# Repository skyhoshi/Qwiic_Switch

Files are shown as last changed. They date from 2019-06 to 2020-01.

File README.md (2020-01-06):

SparkFun Qwiic Switch/Arcade
========================================
<table class="table table-hover table-striped table-bordered">
  <tr align="center">
   <td></td>
   <td></td>
   <td></td>
  </tr>
  <tr align="center">
    <td><a href="https://www.sparkfun.com/products/15591">SparkFun Qwiic Arcade - Red (SPX-15591)</a></td>
    <td><a href="https://www.sparkfun.com/products/15592">SparkFun Qwiic Arcade - Blue (SPX-15592)</a></td>
    <td><a href="https://www.sparkfun.com/products/15586">SparkFun Qwiic Switch (SPX-15586)</a></td>
  </tr>
</table>

The SparkFun Qwiic Switch and Qwiic Arcade are I<sup>2</sup>C enabled boards with interrupts, variable I<sup>2</sup>C addresses, external LED output, and onboard button queues.

Repository Contents
-------------------

* **/Firmware** - Firmware for the built-in ATTiny84 on the Qwiic Button/Switch/Arcade (.h, .ino)
* **/Hardware** - Eagle design files (.brd, .sch)
* **/Hardware/Production** - Production panel files (.brd)

Documentation
--------------
* **[SparkFun Qwiic Button Arduino Library](https://github.com/sparkfun/SparkFun_Qwiic_Button_Arduino_Library)** - Arduino library for the Qwiic Button and Switch.

License Information
-------------------

This product is _**open source**_! 

Please review the LICENSE.md file for license information. 

If you have any questions or concerns on licensing, please contact technical support on our [SparkFun forums](https://forum.sparkfun.com/viewforum.php?f=152).

Distributed as-is; no warranty is given.

- Your friends at SparkFun.

_<COLLABORATION CREDIT>_

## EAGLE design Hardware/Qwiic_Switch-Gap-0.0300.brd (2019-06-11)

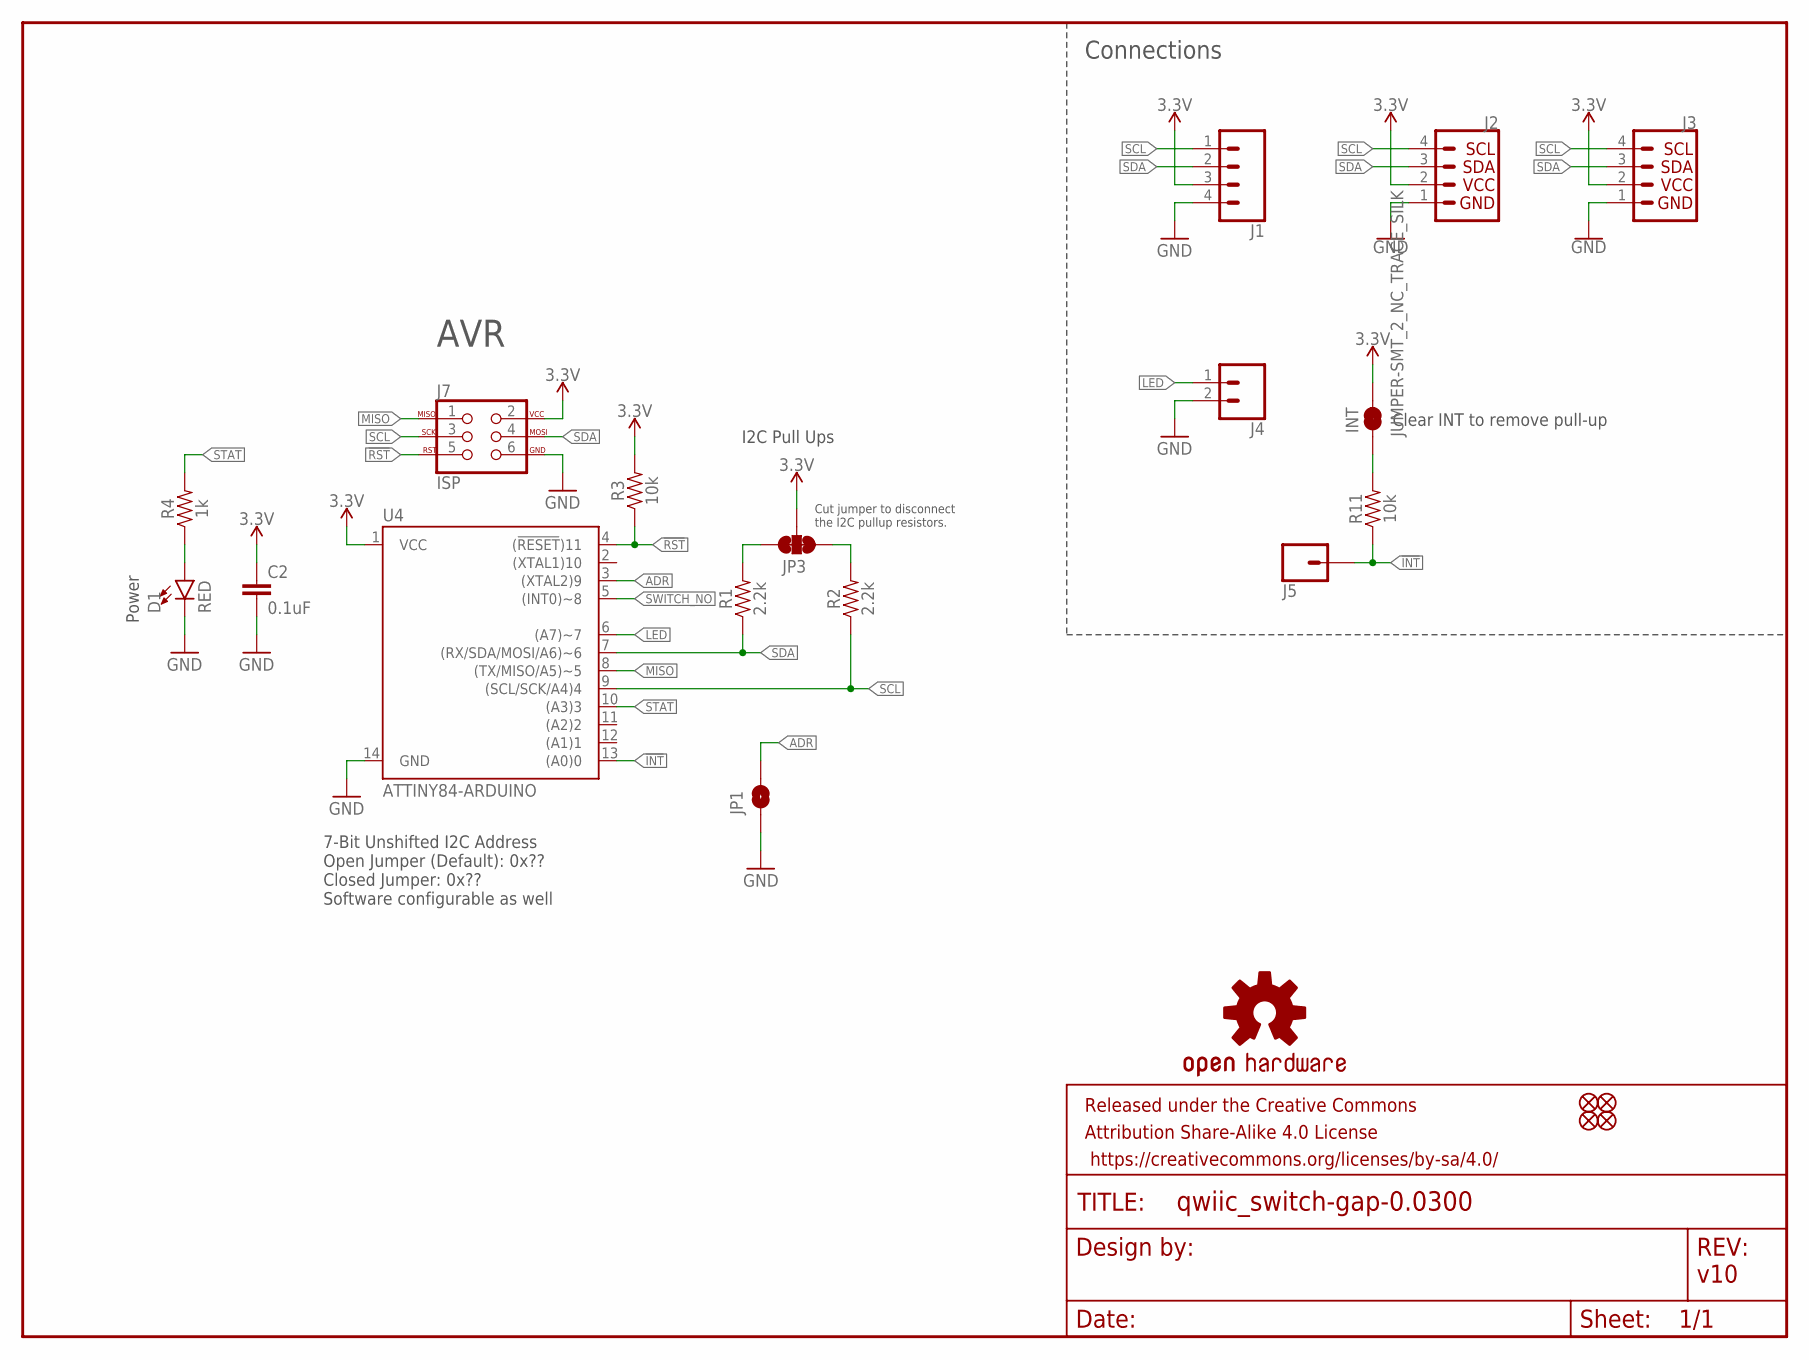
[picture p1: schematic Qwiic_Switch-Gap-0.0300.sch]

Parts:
C2: 0.1uF; 0603
D1: RED; LED-0603
FRAME1: FRAME-LETTER; CREATIVE_COMMONS
INT: JUMPER-SMT_2_NC_TRACE_SILK; SMT-JUMPER_2_NC_TRACE_SILK
J1: CONN_041X04_NO_SILK; 1X04_NO_SILK
J2, J3: QWIIC_CONNECTORJS-1MM; JST04_1MM_RA
J4: CONN_021X02_NO_SILK; 1X02_NO_SILK
J5: CONN_01PTH_NO_SILK_YES_STOP; 1X01_NO_SILK
J7: ISP; 2X3_TEST_POINTS
JP1: JUMPER-SMT_2_NO_SILK; SMT-JUMPER_2_NO_SILK
JP2, JP6, JP8, JP9: FIDUCIALUFIDUCIAL; MICRO-FIDUCIAL
JP3: JUMPER-SMT_3_2-NC_TRACE_SILK; SMT-JUMPER_3_2-NC_TRACE_SILK
LOGO1: OSHW-LOGOMINI; OSHW-LOGO-MINI
R1, R2: 2.2k; 0603
R3, R11: 10k; 0603
R4: 1k; 0603
U4: ATTINY84-ARDUINO; SO14

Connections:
3.3V: C2.1, INT.2, J1.3, J2.2, J3.2, J7.2, JP3.2, R3.2, U4.1 (VCC)
!INT: J5.1, R11.1, U4.13 ((A0)0)
!RST: J7.5, R3.1, U4.4 ((!RESET!)11)
ADR: JP1.2, U4.3 ((XTAL2)9)
GND: C2.2, D1.C, J1.4, J2.1, J3.1, J4.2, J7.6, JP1.1, U4.14 (GND)
INT_R: INT.1, R11.2
LED: J4.1, U4.6 ((A7)~7)
MISO: J7.1, U4.8 ((TX/MISO/A5)~5)
unnamed: D1.A, R4.1
SCL: J1.1, J2.4, J3.4, J7.3, R2.1, U4.9 ((SCL/SCK/A4)4)
SCL_PU1: JP3.1, R2.2
SDA: J1.2, J2.3, J3.3, J7.4, R1.1, U4.7 ((RX/SDA/MOSI/A6)~6)
SDA_PU1: JP3.3, R1.2
STAT: R4.2, U4.10 ((A3)3)
SWITCH_NO: U4.5 ((INT0)~8)

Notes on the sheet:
v10
Connections
Cut jumper to disconnect the I2C pullup resistors.
7-Bit Unshifted I2C Address Open Jumper (Default): 0x?? Closed Jumper: 0x?? Software configurable as well
I2C Pull Ups
AVR
Power
Clear INT to remove pull-up

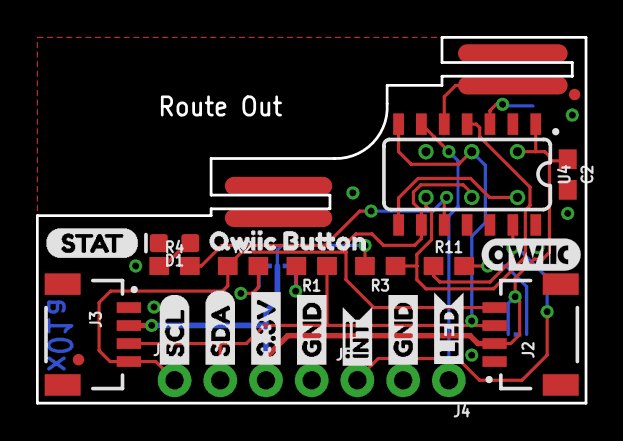
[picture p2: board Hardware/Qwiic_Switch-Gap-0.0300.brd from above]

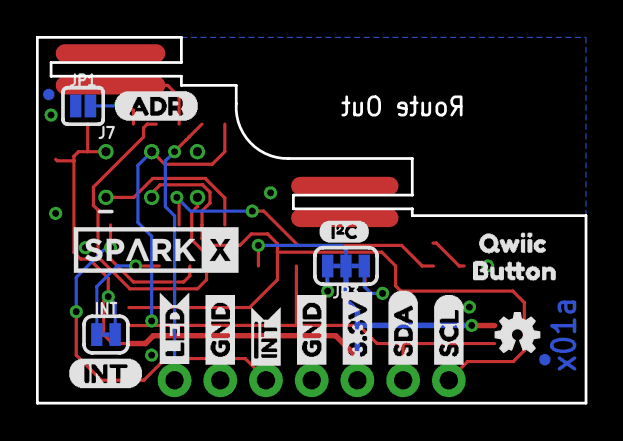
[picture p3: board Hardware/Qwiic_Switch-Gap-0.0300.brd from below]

Board: 2 copper layers, 30.5 x 20.3 mm, 47 parts (20 on the bottom side), 14 nets.

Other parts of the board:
U$1: QWIIC_5.5MM
U$2, U$20: QWIIC0
U$3, U$19: LED2
U$4: INT-()-04
U$5, U$14: SCL
U$6, U$12: SDA
U$7, U$22: 3.3V
U$8, U$13, U$16, U$17: GND
U$9: (ADR)
U$10: I_SUPER2_C-()-03
U$11, U$15: INT#-[<-04
U$18: SPARKX-MEDIUM
U$21: STAT1
U$23, U$24: BUTTON1

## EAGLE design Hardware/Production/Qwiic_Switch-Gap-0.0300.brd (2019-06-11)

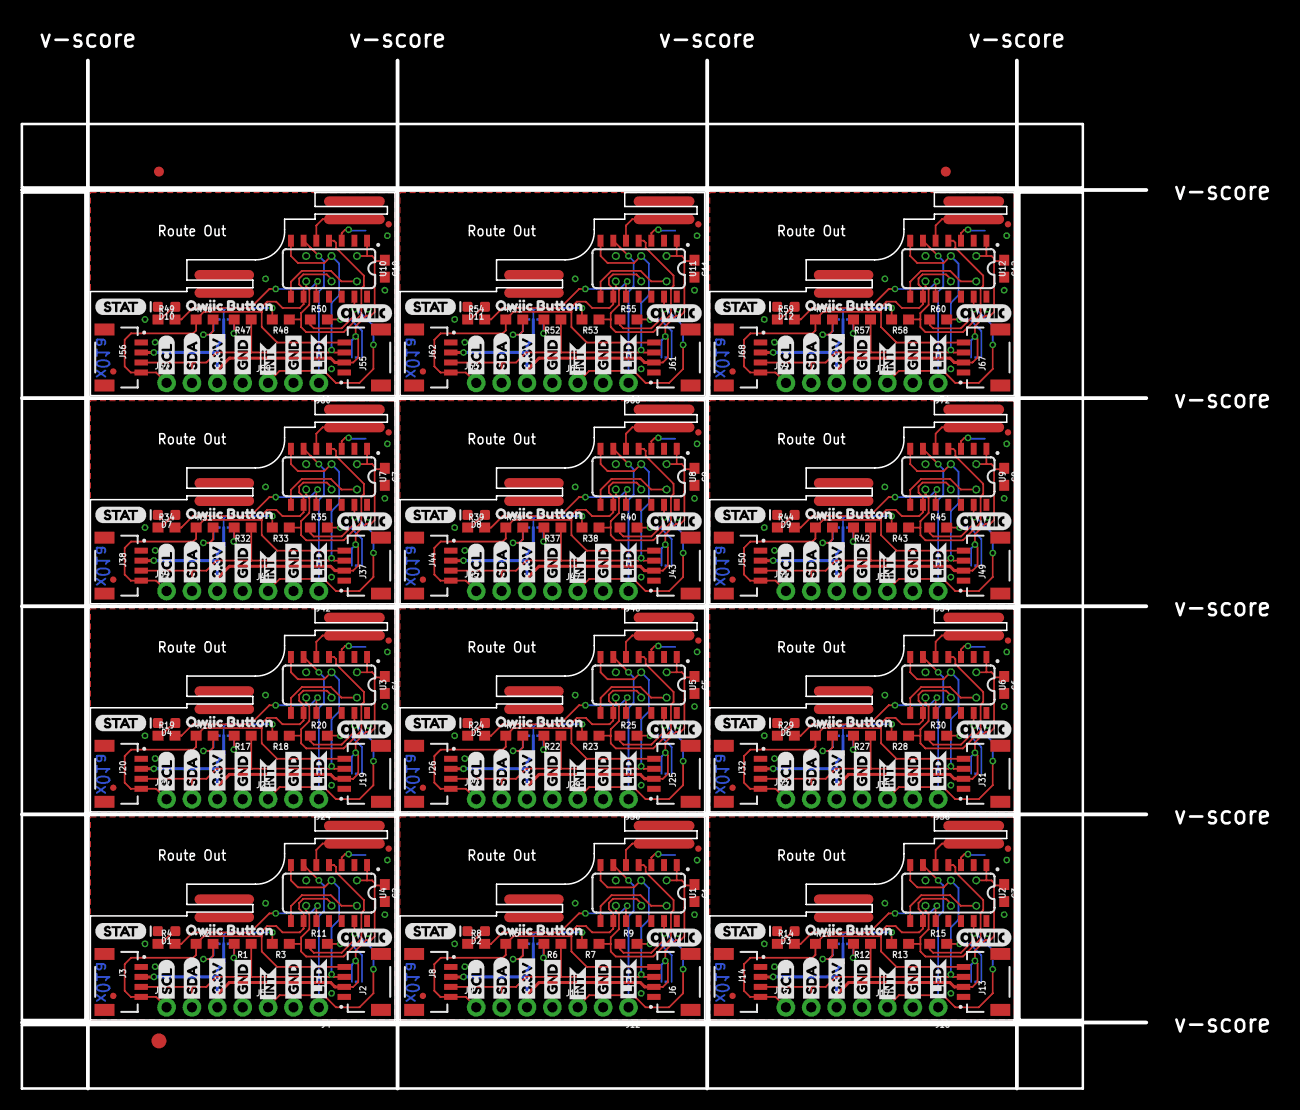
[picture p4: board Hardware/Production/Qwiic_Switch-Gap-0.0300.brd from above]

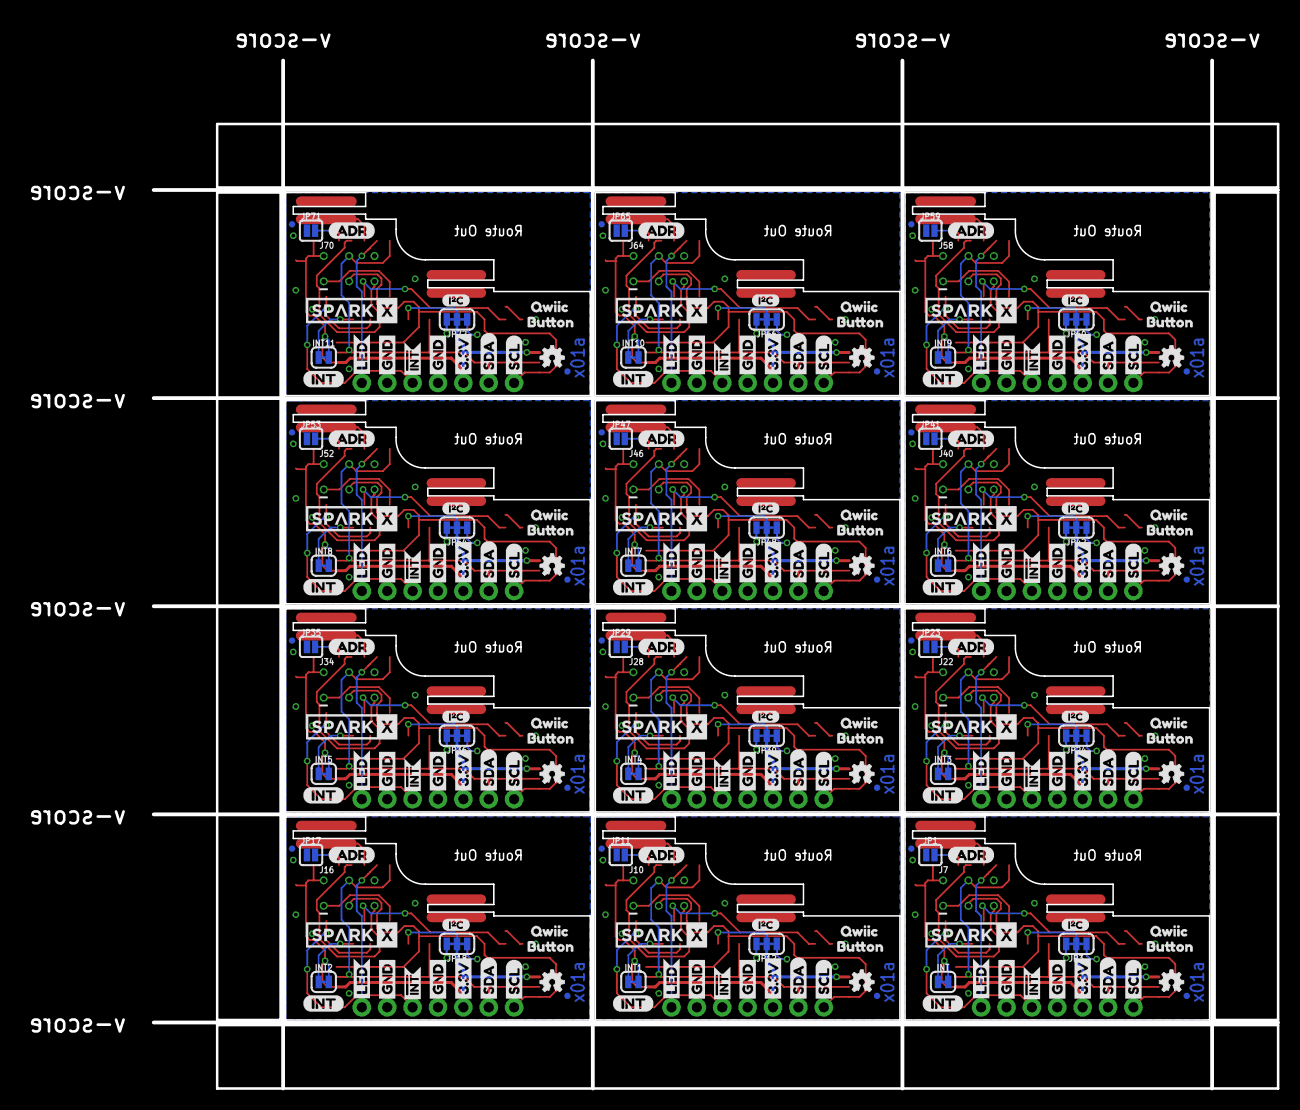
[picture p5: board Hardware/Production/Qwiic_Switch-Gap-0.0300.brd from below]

Board: 2 copper layers, 112.5 x 102.9 mm, 555 parts (240 on the bottom side), 168 nets.

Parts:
C1, C2, C3, C4, C5, C6, C7, C8, C9, C10, C11, C12: 0.1uF; 0603
D1, D2, D3, D4, D5, D6, D7, D8, D9, D10, D11, D12: RED; LED-0603
E$1, E$2: FIDUCIAL-1X2
E$3: FIDUCIAL-1.5X3
INT, INT1, INT2, INT3, INT4, INT5, INT6, INT7, INT8, INT9, INT10, INT11: JUMPER-SMT_2_NC_TRACE_SILK; SMT-JUMPER_2_NC_TRACE_SILK
J1, J9, J15, J21, J27, J33, J39, J45, J51, J57, J63, J69: 1X04_NO_SILK
J2, J3, J6, J8, J13, J14, J19, J20, J25, J26, J31, J32, J37, J38, J43, J44, J49, J50, J55, J56, J61, J62, J67, J68: JST04_1MM_RA
J4, J12, J18, J24, J30, J36, J42, J48, J54, J60, J66, J72: 1X02_NO_SILK
J5, J11, J17, J23, J29, J35, J41, J47, J53, J59, J65, J71: 1X01_NO_SILK
J7, J10, J16, J22, J28, J34, J40, J46, J52, J58, J64, J70: ISP; 2X3_TEST_POINTS
JP1, JP11, JP17, JP23, JP29, JP35, JP41, JP47, JP53, JP59, JP65, JP71: SMT-JUMPER_2_NO_SILK
JP2, JP4, JP5, JP6, JP7, JP8, JP9, JP10, JP13, JP14, JP15, JP16, JP19, JP20, JP21, JP22, JP25, JP26, JP27, JP28, JP31, JP32, JP33, JP34, JP37, JP38, JP39, JP40, JP43, JP44, JP45, JP46, JP49, JP50, JP51, JP52, JP55, JP56, JP57, JP58, JP61, JP62, JP63, JP64, JP67, JP68, JP69, JP70: FIDUCIALUFIDUCIAL; MICRO-FIDUCIAL
JP3, JP12, JP18, JP24, JP30, JP36, JP42, JP48, JP54, JP60, JP66, JP72: SMT-JUMPER_3_2-NC_TRACE_SILK
LOGO1, LOGO2, LOGO3, LOGO4, LOGO5, LOGO6, LOGO7, LOGO8, LOGO9, LOGO10, LOGO11, LOGO12: OSHW-LOGOMINI; OSHW-LOGO-MINI
R1, R2, R5, R6, R10, R12, R16, R17, R21, R22, R26, R27, R31, R32, R36, R37, R41, R42, R46, R47, R51, R52, R56, R57: 2.2k; 0603
R3, R7, R9, R11, R13, R15, R18, R20, R23, R25, R28, R30, R33, R35, R38, R40, R43, R45, R48, R50, R53, R55, R58, R60: 10k; 0603
R4, R8, R14, R19, R24, R29, R34, R39, R44, R49, R54, R59: 1k; 0603
U1, U2, U3, U4, U5, U6, U7, U8, U9, U10, U11, U12: ATTINY84-ARDUINO; SO14
U$1, U$44, U$68, U$92, U$116, U$140, U$164, U$188, U$212, U$236, U$260, U$284: QWIIC_5.5MM
U$2, U$20, U$45, U$46, U$69, U$70, U$93, U$94, U$117, U$118, U$141, U$142, U$165, U$166, U$189, U$190, U$213, U$214, U$237, U$238, U$261, U$262, U$285, U$286: QWIIC0
U$3, U$19, U$41, U$42, U$65, U$66, U$89, U$90, U$113, U$114, U$137, U$138, U$161, U$162, U$185, U$186, U$209, U$210, U$233, U$234, U$257, U$258, U$281, U$282: LED2
U$4, U$40, U$64, U$88, U$112, U$136, U$160, U$184, U$208, U$232, U$256, U$280: INT-()-04
U$5, U$14, U$25, U$35, U$49, U$59, U$73, U$83, U$97, U$107, U$121, U$131, U$145, U$155, U$169, U$179, U$193, U$203, U$217, U$227, U$241, U$251, U$265, U$275: SCL
U$6, U$12, U$26, U$34, U$50, U$58, U$74, U$82, U$98, U$106, U$122, U$130, U$146, U$154, U$170, U$178, U$194, U$202, U$218, U$226, U$242, U$250, U$266, U$274: SDA
U$7, U$22, U$27, U$31, U$51, U$55, U$75, U$79, U$99, U$103, U$123, U$127, U$147, U$151, U$171, U$175, U$195, U$199, U$219, U$223, U$243, U$247, U$267, U$271: 3.3V
U$8, U$13, U$16, U$17, U$28, U$30, U$37, U$38, U$52, U$54, U$61, U$62, U$76, U$78, U$85, U$86, U$100, U$102, U$109, U$110, U$124, U$126, U$133, U$134, U$148, U$150, U$157, U$158, U$172, U$174, U$181, U$182, U$196, U$198, U$205, U$206, U$220, U$222, U$229, U$230, U$244, U$246, U$253, U$254, U$268, U$270, U$277, U$278: GND
U$9, U$29, U$53, U$77, U$101, U$125, U$149, U$173, U$197, U$221, U$245, U$269: (ADR)
U$10, U$32, U$56, U$80, U$104, U$128, U$152, U$176, U$200, U$224, U$248, U$272: I_SUPER2_C-()-03
U$11, U$15, U$33, U$36, U$57, U$60, U$81, U$84, U$105, U$108, U$129, U$132, U$153, U$156, U$177, U$180, U$201, U$204, U$225, U$228, U$249, U$252, U$273, U$276: INT#-[<-04
U$18, U$39, U$63, U$87, U$111, U$135, U$159, U$183, U$207, U$231, U$255, U$279: SPARKX-MEDIUM
U$21, U$43, U$67, U$91, U$115, U$139, U$163, U$187, U$211, U$235, U$259, U$283: STAT1
U$23, U$24, U$47, U$48, U$71, U$72, U$95, U$96, U$119, U$120, U$143, U$144, U$167, U$168, U$191, U$192, U$215, U$216, U$239, U$240, U$263, U$264, U$287, U$288: BUTTON1

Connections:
3.3V: C2.1, INT.2, J1.3, J2.2, J3.2, J7.2, JP3.2, R3.2, U4.1
3.3V1: C1.1, INT1.2, J6.2, J8.2, J9.3, J10.2, JP12.2, R7.2, U1.1
3.3V2: C3.1, INT2.2, J13.2, J14.2, J15.3, J16.2, JP18.2, R13.2, U2.1
3.3V3: C4.1, INT3.2, J19.2, J20.2, J21.3, J22.2, JP24.2, R18.2, U3.1
3.3V4: C5.1, INT4.2, J25.2, J26.2, J27.3, J28.2, JP30.2, R23.2, U5.1
3.3V5: C6.1, INT5.2, J31.2, J32.2, J33.3, J34.2, JP36.2, R28.2, U6.1
3.3V6: C7.1, INT6.2, J37.2, J38.2, J39.3, J40.2, JP42.2, R33.2, U7.1
3.3V7: C8.1, INT7.2, J43.2, J44.2, J45.3, J46.2, JP48.2, R38.2, U8.1
3.3V8: C9.1, INT8.2, J49.2, J50.2, J51.3, J52.2, JP54.2, R43.2, U9.1
3.3V9: C10.1, INT9.2, J55.2, J56.2, J57.3, J58.2, JP60.2, R48.2, U10.1
3.3V10: C11.1, INT10.2, J61.2, J62.2, J63.3, J64.2, JP66.2, R53.2, U11.1
3.3V11: C12.1, INT11.2, J67.2, J68.2, J69.3, J70.2, JP72.2, R58.2, U12.1
!INT: J5.1, R11.1, U4.13
!INT1: J11.1, R9.1, U1.13
!INT2: J17.1, R15.1, U2.13
!INT3: J23.1, R20.1, U3.13
!INT4: J29.1, R25.1, U5.13
!INT5: J35.1, R30.1, U6.13
!INT6: J41.1, R35.1, U7.13
!INT7: J47.1, R40.1, U8.13
!INT8: J53.1, R45.1, U9.13
!INT9: J59.1, R50.1, U10.13
!INT10: J65.1, R55.1, U11.13
!INT11: J71.1, R60.1, U12.13
!RST: J7.5, R3.1, U4.4
!RST1: J10.5, R7.1, U1.4
!RST2: J16.5, R13.1, U2.4
!RST3: J22.5, R18.1, U3.4
!RST4: J28.5, R23.1, U5.4
!RST5: J34.5, R28.1, U6.4
!RST6: J40.5, R33.1, U7.4
!RST7: J46.5, R38.1, U8.4
!RST8: J52.5, R43.1, U9.4
!RST9: J58.5, R48.1, U10.4
!RST10: J64.5, R53.1, U11.4
!RST11: J70.5, R58.1, U12.4
ADR: JP1.2, U4.3
ADR1: JP11.2, U1.3
ADR2: JP17.2, U2.3
ADR3: JP23.2, U3.3
ADR4: JP29.2, U5.3
ADR5: JP35.2, U6.3
ADR6: JP41.2, U7.3
ADR7: JP47.2, U8.3
ADR8: JP53.2, U9.3
ADR9: JP59.2, U10.3
ADR10: JP65.2, U11.3
ADR11: JP71.2, U12.3
GND: C2.2, D1.C, J1.4, J2.1, J3.1, J4.2, J7.6, JP1.1, U4.14
GND1: C1.2, D2.C, J6.1, J8.1, J9.4, J10.6, J12.2, JP11.1, U1.14
GND2: C3.2, D3.C, J13.1, J14.1, J15.4, J16.6, J18.2, JP17.1, U2.14
GND3: C4.2, D4.C, J19.1, J20.1, J21.4, J22.6, J24.2, JP23.1, U3.14
GND4: C5.2, D5.C, J25.1, J26.1, J27.4, J28.6, J30.2, JP29.1, U5.14
GND5: C6.2, D6.C, J31.1, J32.1, J33.4, J34.6, J36.2, JP35.1, U6.14
GND6: C7.2, D7.C, J37.1, J38.1, J39.4, J40.6, J42.2, JP41.1, U7.14
GND7: C8.2, D8.C, J43.1, J44.1, J45.4, J46.6, J48.2, JP47.1, U8.14
GND8: C9.2, D9.C, J49.1, J50.1, J51.4, J52.6, J54.2, JP53.1, U9.14
GND9: C10.2, D10.C, J55.1, J56.1, J57.4, J58.6, J60.2, JP59.1, U10.14
GND10: C11.2, D11.C, J61.1, J62.1, J63.4, J64.6, J66.2, JP65.1, U11.14
GND11: C12.2, D12.C, J67.1, J68.1, J69.4, J70.6, J72.2, JP71.1, U12.14
INT_R: INT.1, R11.2
INT_R1: INT1.1, R9.2
INT_R2: INT2.1, R15.2
INT_R3: INT3.1, R20.2
INT_R4: INT4.1, R25.2
INT_R5: INT5.1, R30.2
INT_R6: INT6.1, R35.2
INT_R7: INT7.1, R40.2
INT_R8: INT8.1, R45.2
INT_R9: INT9.1, R50.2
INT_R10: INT10.1, R55.2
INT_R11: INT11.1, R60.2
LED: J4.1, U4.6
LED1: J12.1, U1.6
LED2: J18.1, U2.6
LED3: J24.1, U3.6
LED4: J30.1, U5.6
LED5: J36.1, U6.6
LED6: J42.1, U7.6
LED7: J48.1, U8.6
LED8: J54.1, U9.6
LED9: J60.1, U10.6
LED10: J66.1, U11.6
LED11: J72.1, U12.6
MISO: J7.1, U4.8
MISO1: J10.1, U1.8
MISO2: J16.1, U2.8
MISO3: J22.1, U3.8
MISO4: J28.1, U5.8
MISO5: J34.1, U6.8
MISO6: J40.1, U7.8
MISO7: J46.1, U8.8
MISO8: J52.1, U9.8
MISO9: J58.1, U10.8
MISO10: J64.1, U11.8
MISO11: J70.1, U12.8
unnamed: D2.A, R8.1
unnamed: D1.A, R4.1
unnamed: D3.A, R14.1
unnamed: D4.A, R19.1
unnamed: D5.A, R24.1
unnamed: D6.A, R29.1
unnamed: D7.A, R34.1
unnamed: D8.A, R39.1
unnamed: D9.A, R44.1
unnamed: D10.A, R49.1
unnamed: D11.A, R54.1
unnamed: D12.A, R59.1
SCL: J1.1, J2.4, J3.4, J7.3, R2.1, U4.9
SCL1: J6.4, J8.4, J9.1, J10.3, R5.1, U1.9
SCL2: J13.4, J14.4, J15.1, J16.3, R10.1, U2.9
SCL3: J19.4, J20.4, J21.1, J22.3, R16.1, U3.9
SCL4: J25.4, J26.4, J27.1, J28.3, R21.1, U5.9
SCL5: J31.4, J32.4, J33.1, J34.3, R26.1, U6.9
SCL6: J37.4, J38.4, J39.1, J40.3, R31.1, U7.9
SCL7: J43.4, J44.4, J45.1, J46.3, R36.1, U8.9
SCL8: J49.4, J50.4, J51.1, J52.3, R41.1, U9.9
SCL9: J55.4, J56.4, J57.1, J58.3, R46.1, U10.9
SCL10: J61.4, J62.4, J63.1, J64.3, R51.1, U11.9
SCL11: J67.4, J68.4, J69.1, J70.3, R56.1, U12.9
SCL_PU1: JP3.1, R2.2
SCL_PU2: JP12.1, R5.2
SCL_PU3: JP18.1, R10.2
SCL_PU4: JP24.1, R16.2
SCL_PU5: JP30.1, R21.2
SCL_PU6: JP36.1, R26.2
SCL_PU7: JP42.1, R31.2
SCL_PU8: JP48.1, R36.2
SCL_PU9: JP54.1, R41.2
SCL_PU10: JP60.1, R46.2
SCL_PU11: JP66.1, R51.2
SCL_PU12: JP72.1, R56.2
SDA: J1.2, J2.3, J3.3, J7.4, R1.1, U4.7
SDA1: J6.3, J8.3, J9.2, J10.4, R6.1, U1.7
SDA2: J13.3, J14.3, J15.2, J16.4, R12.1, U2.7
SDA3: J19.3, J20.3, J21.2, J22.4, R17.1, U3.7
SDA4: J25.3, J26.3, J27.2, J28.4, R22.1, U5.7
SDA5: J31.3, J32.3, J33.2, J34.4, R27.1, U6.7
SDA6: J37.3, J38.3, J39.2, J40.4, R32.1, U7.7
SDA7: J43.3, J44.3, J45.2, J46.4, R37.1, U8.7
SDA8: J49.3, J50.3, J51.2, J52.4, R42.1, U9.7
SDA9: J55.3, J56.3, J57.2, J58.4, R47.1, U10.7
SDA10: J61.3, J62.3, J63.2, J64.4, R52.1, U11.7
SDA11: J67.3, J68.3, J69.2, J70.4, R57.1, U12.7
SDA_PU1: JP3.3, R1.2
SDA_PU2: JP12.3, R6.2
SDA_PU3: JP18.3, R12.2
SDA_PU4: JP24.3, R17.2
SDA_PU5: JP30.3, R22.2
SDA_PU6: JP36.3, R27.2
SDA_PU7: JP42.3, R32.2
SDA_PU8: JP48.3, R37.2
SDA_PU9: JP54.3, R42.2
SDA_PU10: JP60.3, R47.2
SDA_PU11: JP66.3, R52.2
SDA_PU12: JP72.3, R57.2
STAT: R4.2, U4.10
STAT1: R8.2, U1.10
STAT2: R14.2, U2.10
STAT3: R19.2, U3.10
STAT4: R24.2, U5.10
STAT5: R29.2, U6.10
STAT6: R34.2, U7.10
STAT7: R39.2, U8.10
STAT8: R44.2, U9.10
STAT9: R49.2, U10.10
STAT10: R54.2, U11.10
STAT11: R59.2, U12.10

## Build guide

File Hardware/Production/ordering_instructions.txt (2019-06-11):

panel size, 107x97mm
PCB thickness, 1.6mm
number of layers, 2
soldermask color, Black
silkscreen color, White
oz copper, 1oz
finish, HASL lead free
stencils, top+bottom
pcs per panel, 12
min trace width, 0.177800mm / 0.007000in
min drill size, 0.381000mm / 0.015000in

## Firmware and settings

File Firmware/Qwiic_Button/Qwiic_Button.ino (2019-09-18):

/*
  An I2C based Button
  By: Nathan Seidle and Fischer Moseley and Priyanka Makin
  SparkFun Electronics
  Date: July 31st, 2019
  License: This code is public domain but you buy me a beer if you use this and
  we meet someday (Beerware license).

  Qwiic Button is an I2C based button that records any button presses to a queue.

  Qwiic Button maintains a queue of events. To remove events from the queue write
  the appropriate register (timeSinceLastButtonClicked or timeSinceLastButtonPressed)
  to zero. The register will then be filled with the next available event time.

  There is also an accompanying Arduino Library located here:
  https://github.com/sparkfun/SparkFun_Qwiic_Button_Arduino_Library

  Feel like supporting our work? Buy a board from SparkFun!
  https://www.sparkfun.com/products/14641

  To install support for ATtiny84 in Arduino IDE: https://github.com/SpenceKonde/ATTinyCore/blob/master/Installation.md
  This core is installed from the Board Manager menu
  This core has built in support for I2C S/M and serial
  If you have Dave Mellis' ATtiny installed you may need to remove it from \Users\xx\AppData\Local\Arduino15\Packages

  To support 400kHz I2C communication reliably ATtiny84 needs to run at 8MHz. This requires user to
  click on 'Burn Bootloader' before code is loaded.

  Library Inclusion:
  Wire.h        Used for interfacing with the I2C hardware for responding to I2C events.
  EEPROM.h      Used for interfacing with the onboard EEPROM for storing and retrieving settings.
  nvm.h         Used for defining the storage locations in non-volatile memory (EEPROM) to store and retrieve settings from.
  queue.h       Used for defining a FIFO-queue that contains the timestamps associated with pressing and clicking the button.
  registers.h   Used for defining a memoryMap object that serves as the register map for the device.
  led.h         Used for configuring the behavior of the onboard LED (in the case of the Qwiic Button)
                  or the offboard LED (in the case of the Qwiic Switch)

  PinChangeInterrupt.h    Nico Hoo's library for triggering an interrupt on a pin state change (either low->high or high->low)
  avr/sleep.h             Needed for sleep_mode which saves power on the ATTiny
  avr/power.hardware      Needed for powering down peripherals such as the ADC/TWI and Timers on the ATTiny
*/

#include <Wire.h>
#include <EEPROM.h>
#include "nvm.h"
#include "queue.h"
#include "registers.h"
#include "led.h"

#include "PinChangeInterrupt.h" //Nico Hood's library: https://github.com/NicoHood/PinChangeInterrupt/
//Used for pin change interrupts on ATtinys (encoder button causes interrupt)
//Note: To make this code work with Nico's library you have to comment out https://github.com/NicoHood/PinChangeInterrupt/blob/master/src/PinChangeInterruptSettings.h#L228

#include <avr/sleep.h> //Needed for sleep_mode
#include <avr/power.h> //Needed for powering down perihperals such as the ADC/TWI and Timers

#define DEVICE_ID 0x5D
#define FIRMWARE_MAJOR 0x01 //Firmware Version. Helpful for tech support.
#define FIRMWARE_MINOR 0x01

#define DEFAULT_I2C_ADDRESS 0x6F

//Hardware connections
#if defined(__AVR_ATmega328P__)
//For developement on an Uno
const uint8_t addressPin0 = 3;
const uint8_t addressPin1 = 4;
const uint8_t addressPin2 = 5;
const uint8_t addressPin3 = 6;
const uint8_t ledPin = 9; //PWM
const uint8_t statusLedPin = 8;
const uint8_t switchPin = 2;
const uint8_t interruptPin = 7; //pin is active-low, high-impedance when not triggered, goes low-impedance to ground when triggered

#elif defined(__AVR_ATtiny84__)
const uint8_t addressPin0 = 9;
const uint8_t addressPin1 = 10;
const uint8_t addressPin2 = 1;
const uint8_t addressPin3 = 2;
const uint8_t ledPin = 7; //PWM
const uint8_t statusLedPin = 3;
const uint8_t switchPin = 8;
const uint8_t interruptPin = 0; //pin is active-low, high-impedance when not triggered, goes low-impedance to ground when triggered
#endif

//Global variables
//-=-=-=-=-=-=-=-=-=-=-=-=-=-=-=-=-=-=-=-=-=-=-=-=-=-=-=-=-=-=-=-=-=-=-=-=-=-=-=-=-=-=-=-=-=-
//These are the defaults for all settings

//Variables used in the I2C interrupt.ino file so we use volatile
volatile memoryMap registerMap {
  DEVICE_ID,           //id
  FIRMWARE_MINOR,      //firmwareMinor
  FIRMWARE_MAJOR,      //firmwareMajor
  {0, 0, 0},           //buttonStatus {isPressed, hasBeenClicked, eventAvailable}
  {1, 1},              //interruptConfig {pressedEnable, clickedEnable}
  0x000A,              //buttonDebounceTime
  {0, 1, 0},           //pressedQueueStatus {isFull, isEmpty, popRequest}
  0x00000000,          //pressedQueueFront
  0x00000000,          //pressedQueueBack
  {0, 1, 0},           //clickedQueueStatus {isFull, isEmpty, popRequest}
  0x00000000,          //clickedQueueFront
  0x00000000,          //clickedQueueBack
  0x00,                //ledBrightness
  0x01,                //ledPulseGranularity
  0x0000,              //ledPulseCycleTime
  0x0000,              //ledPulseOffTime
  DEFAULT_I2C_ADDRESS, //i2cAddress
};

//This defines which of the registers are read-only (0) vs read-write (1)
memoryMap protectionMap = {
  0x00,       //id
  0x00,       //firmwareMinor
  0x00,       //firmwareMajor
  {1, 1, 1},  //buttonStatus {isPressed, hasBeenClicked, eventAvailable}
  {1, 1},     //interruptConfig {pressedEnable, clickedEnable}
  0xFFFF,     //buttonDebounceTime
  {0, 0, 1},  //pressedQueueStatus {isFull, isEmpty, popRequest}
  0x00000000, //pressedQueueFront
  0x00000000, //pressedQueueBack
  {0, 0, 1},  //clickedQueueStatus {isFull, isEmpty, popRequest}
  0x00000000, //clickedQueueFront
  0x00000000, //clickedQueueBack
  0xFF,       //ledBrightness
  0xFF,       //ledPulseGranularity
  0xFFFF,     //ledPulseCycleTime
  0xFFFF,     //ledPulseOffTime
  0xFF,       //i2cAddress

};

//Cast 32bit address of the object registerMap with uint8_t so we can increment the pointer
uint8_t *registerPointer = (uint8_t *)&registerMap;
uint8_t *protectionPointer = (uint8_t *)&protectionMap;

volatile uint8_t registerNumber; //Gets set when user writes an address. We then serve the spot the user requested.

volatile boolean updateFlag = true; //Goes true when we receive new bytes from user. Causes LEDs and things to update in main loop.

volatile Queue ButtonPressed, ButtonClicked; //Init FIFO buffer for storing timestamps associated with button presses and clicks

volatile unsigned long lastClickTime = 0; //Used for debouncing

LEDconfig onboardLED; //init the onboard LED

//-=-=-=-=-=-=-=-=-=-=-=-=-=-=-=-=-=-=-=-=-=-=-=-=-=-=-=-=-=-=-=-=-=-=-=-=-=-=-=-=-=-=-=-=-=-

void setup(void)
{
  pinMode(addressPin0, INPUT_PULLUP); //Internally pull up address pins
  pinMode(addressPin1, INPUT_PULLUP);
  pinMode(addressPin2, INPUT_PULLUP);
  pinMode(addressPin3, INPUT_PULLUP);

  pinMode(ledPin, OUTPUT); //PWM
  analogWrite(ledPin, 0);

  pinMode(statusLedPin, OUTPUT); //No PWM
  digitalWrite(statusLedPin, 0);

  pinMode(switchPin, INPUT_PULLUP); //GPIO with internal pullup, goes low when button is pushed
#if defined(__AVR_ATmega328P__)
  pinMode(interruptPin, INPUT_PULLUP);     //High-impedance input until we have an int and then we output low. Pulled high with 10k with cuttable jumper.
#else
  pinMode(interruptPin, INPUT);     //High-impedance input until we have an int and then we output low. Pulled high with 10k with cuttable jumper.
#endif

  //Disable ADC
  ADCSRA = 0;

  //Disable Brown-Out Detect
  MCUCR = bit(BODS) | bit(BODSE);
  MCUCR = bit(BODS);

  //Power down various bits of hardware to lower power usage
  //set_sleep_mode(SLEEP_MODE_PWR_DOWN); //May turn off millis
  set_sleep_mode(SLEEP_MODE_IDLE);
  sleep_enable();

#if defined(__AVR_ATmega328P__)

  for (int x = 0; x < 100; x++) {
    EEPROM.put(x, 0xFF);
  }

  Serial.begin(115200);
  Serial.println("Qwiic Button");
  Serial.print("Address: 0x");
  Serial.println(registerMap.i2cAddress, HEX);
  Serial.print("Device ID: 0x");
  Serial.println(registerMap.id, HEX);

#endif

  readSystemSettings(&registerMap); //Load all system settings from EEPROM

#if defined(__AVR_ATmega328P__)
  //Debug values
  registerMap.ledBrightness = 255;     //Max brightness
  registerMap.ledPulseGranularity = 1; //Amount to change LED at each step

  registerMap.ledPulseCycleTime = 500; //Total amount of cycle, does not include off time. LED pulse disabled if zero.
  registerMap.ledPulseOffTime = 500;   //Off time between pulses
#endif

  onboardLED.update(&registerMap); //update LED variables, get ready for pulsing
  setupInterrupts();               //Enable pin change interrupts for I2C, switch, etc
  startI2C(&registerMap);          //Determine the I2C address we should be using and begin listening on I2C bus



  digitalWrite(statusLedPin, HIGH); //turn on the status LED to notify that we've setup everything properly
}

void loop(void)
{

  //update interruptPin output
  if ((registerMap.buttonStatus.isPressed && registerMap.interruptConfigure.pressedEnable) ||
      (registerMap.buttonStatus.hasBeenClicked && registerMap.interruptConfigure.clickedEnable))
  { //if the interrupt is triggered
    pinMode(interruptPin, OUTPUT); //make the interrupt pin a low-impedance connection to ground
    digitalWrite(interruptPin, LOW);
  }
  else
  { //go to high-impedance mode on the interrupt pin if the interrupt is not triggered
#if defined(__AVR_ATmega328P__)
    pinMode(interruptPin, INPUT_PULLUP);
#else
    pinMode(interruptPin, INPUT);
#endif
  }

  if (updateFlag == true)
  {

    


    //Record anything new to EEPROM (like new LED values)
    //It can take ~3.4ms to write a byte to EEPROM so we do that here instead of in an interrupt
    recordSystemSettings(&registerMap);

    //Calculate LED values based on pulse settings if anything has changed
    onboardLED.update(&registerMap);

    updateFlag = false; //clear flag
  }

  sleep_mode();             //Stop everything and go to sleep. Wake up if I2C event occurs.
  onboardLED.pulse(ledPin); //update the brightness of the LED
}

//Update slave I2C address to what's configured with registerMap.i2cAddress and/or the address jumpers.
void startI2C(memoryMap *map)
{
  uint8_t address;

  //Button PCB has 4 jumpers, the arcade/micro switch PCB has one. But we check all pins even when there
  //is no jumper (will always be high).
  uint8_t IOaddress = DEFAULT_I2C_ADDRESS;
  bitWrite(IOaddress, 0, digitalRead(addressPin0));
  bitWrite(IOaddress, 1, digitalRead(addressPin1));
  bitWrite(IOaddress, 2, digitalRead(addressPin2));
  bitWrite(IOaddress, 3, digitalRead(addressPin3));

  //If any of the address jumpers are set, we use jumpers
  if (IOaddress != DEFAULT_I2C_ADDRESS)
  {
    address = IOaddress;
  }

  //If none of the address jumpers are set, we use registerMap (but check to make sure that the value is legal first)
  else
  {
    //if the value is legal, then set it
    if (map->i2cAddress > 0x07 && map->i2cAddress < 0x78)
      address = map->i2cAddress;

    //if the value is illegal, default to the default I2C address for our platform
    else
      address = DEFAULT_I2C_ADDRESS;
  }

  //save new address to the register map
  map->i2cAddress = address;

  //reconfigure Wire instance
  Wire.end();          //stop I2C on old address
  Wire.begin(address); //rejoin the I2C bus on new address

  //The connections to the interrupts are severed when a Wire.begin occurs, so here we reattach them
  Wire.onReceive(receiveEvent);
  Wire.onRequest(requestEvent);
}

//Reads the current system settings from EEPROM
//If anything looks weird, reset setting to default value
void readSystemSettings(memoryMap *map)
{
  //Read what I2C address we should use
  EEPROM.get(LOCATION_I2C_ADDRESS, map->i2cAddress);
  if (map->i2cAddress == 255)
  {
    map->i2cAddress = DEFAULT_I2C_ADDRESS; //By default, we listen for DEFAULT_I2C_ADDRESS
    EEPROM.put(LOCATION_I2C_ADDRESS, map->i2cAddress);
  }

  //Error check I2C address we read from EEPROM
  if (map->i2cAddress < 0x08 || map->i2cAddress > 0x77)
  {
    //User has set the address out of range
    //Go back to defaults
    map->i2cAddress = DEFAULT_I2C_ADDRESS;
    EEPROM.put(LOCATION_I2C_ADDRESS, map->i2cAddress);
  }

  //Read the interrupt bits
  EEPROM.get(LOCATION_INTERRUPTS, map->interruptConfigure.byteWrapped);
  if (map->interruptConfigure.byteWrapped == 0xFF)
  {
    map->interruptConfigure.byteWrapped = 0x03; //By default, enable the click and pressed interrupts
    EEPROM.put(LOCATION_INTERRUPTS, map->interruptConfigure.byteWrapped);
  }

  EEPROM.get(LOCATION_LED_PULSEGRANULARITY, map->ledPulseGranularity);
  if (map->ledPulseGranularity == 0xFF)
  {
    map->ledPulseGranularity = 0; //Default to none
    EEPROM.put(LOCATION_LED_PULSEGRANULARITY, map->ledPulseGranularity);
  }

  EEPROM.get(LOCATION_LED_PULSECYCLETIME, map->ledPulseCycleTime);
  if (map->ledPulseCycleTime == 0xFFFF)
  {
    map->ledPulseCycleTime = 0; //Default to none
    EEPROM.put(LOCATION_LED_PULSECYCLETIME, map->ledPulseCycleTime);
  }

  EEPROM.get(LOCATION_LED_PULSEOFFTIME, map->ledPulseOffTime);
  if (map->ledPulseOffTime == 0xFFFF)
  {
    map->ledPulseOffTime = 0; //Default to none
    EEPROM.put(LOCATION_LED_PULSECYCLETIME, map->ledPulseOffTime);
  }

  EEPROM.get(LOCATION_BUTTON_DEBOUNCE_TIME, map->buttonDebounceTime);
  if (map->buttonDebounceTime == 0xFFFF)
  {
    map->buttonDebounceTime = 10; //Default to 10ms
    EEPROM.put(LOCATION_BUTTON_DEBOUNCE_TIME, map->buttonDebounceTime);
  }

  //Read the starting value for the LED
  EEPROM.get(LOCATION_LED_BRIGHTNESS, map->ledBrightness);
  if (map->ledPulseCycleTime > 0)
  {
    //Don't turn on LED, we'll pulse it in main loop
    analogWrite(ledPin, 0);
  }
  else
  { //Pulsing disabled
    //Turn on LED to setting
    analogWrite(ledPin, map->ledBrightness);
  }
}

//If the current setting is different from that in EEPROM, update EEPROM
void recordSystemSettings(memoryMap *map)
{
  //I2C address is byte
  byte i2cAddr;

  //Error check the current I2C address
  if (map->i2cAddress >= 0x08 && map->i2cAddress <= 0x77)
  {
    //Address is valid

    //Read the value currently in EEPROM. If it's different from the memory map then record the memory map value to EEPROM.
    EEPROM.get(LOCATION_I2C_ADDRESS, i2cAddr);
    if (i2cAddr != map->i2cAddress)
    {
      EEPROM.put(LOCATION_I2C_ADDRESS, (byte)map->i2cAddress);
      startI2C(map); //Determine the I2C address we should be using and begin listening on I2C bus
    }
  }
  else
  {
    EEPROM.get(LOCATION_I2C_ADDRESS, i2cAddr);
    map->i2cAddress == i2cAddr; //Return to original address
  }


  EEPROM.put(LOCATION_INTERRUPTS, map->interruptConfigure.byteWrapped);
  EEPROM.put(LOCATION_LED_BRIGHTNESS, map->ledBrightness);
  EEPROM.put(LOCATION_LED_PULSEGRANULARITY, map->ledPulseGranularity);
  EEPROM.put(LOCATION_LED_PULSECYCLETIME, map->ledPulseCycleTime);
  EEPROM.put(LOCATION_LED_PULSEOFFTIME, map->ledPulseOffTime);
  EEPROM.put(LOCATION_BUTTON_DEBOUNCE_TIME, map->buttonDebounceTime);
}

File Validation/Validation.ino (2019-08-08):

/******************************************************************************
Validates that the attached device is working.

Fischer Moseley @ SparkFun Electronics
Original Creation Date: August 8, 2019

This code is Lemonadeware; if you see me (or any other SparkFun employee) at the
local, and you've found our code helpful, please buy us a round!

Hardware Connections:
Attach the Qwiic Shield to your Arduino/Photon/ESP32 or other
Plug the button into the shield
Print it to the serial monitor at 115200 baud.

Distributed as-is; no warranty is given.
******************************************************************************/

#define I2C_ADDRESS DEFAULT_BUTTON_ADDRESS //change to DEFAULT_SWITCH_ADDRESS if you're using Qwiic Switch or Qwiic Arcade

#include <SparkFun_Qwiic_Button.h>
QwiicButton button;

void setup(){
    Serial.begin(115200);
    Wire.begin(); //Join I2C bus
    Wire.setClock(400000); //Set I2C clock speed to 400kHz
    button.begin(I2C_ADDRESS);

    //reset to default settings
    button.setDebounceTime(10);
    button.LEDconfig(0,1,0,0);
    button.resetInterruptConfig();

    //check if button will acknowledge over I2C
    if(button.isConnected()){
        Serial.println("Device will acknowledge!");
    }

    else {
        Serial.println("Device did not acknowledge! Freezing.");
        while(1);
    }
}

void loop(){
    if(button.isPressed()) button.LEDon(200);
    if(!button.isPressed()) button.LEDoff();

    if(button.isPressedQueueEmpty() == false) { //if the queue of pressed events is not empty
        //then print the time since the last and first button press
        Serial.print(button.timeSinceLastPress()/1000.0);
        Serial.print("s since the button was last pressed   ");
        Serial.print(button.timeSinceFirstPress()/1000.0);
        Serial.print("s since the button was first pressed   ");
    }
    
    //if the queue of pressed events is empty, just print that the queue is empty!
    if(button.isPressedQueueEmpty() == true) {
        Serial.print("ButtonPressed Queue is empty! ");
    } 

    if(button.isClickedQueueEmpty() == false) { //if the queue of clicked events is not empty
        //then print the time since the last and first button click
        Serial.print(button.timeSinceLastClick()/1000.0);
        Serial.print("s since the button was last clicked   ");
        Serial.print(button.timeSinceFirstClick()/1000.0);
        Serial.print("s since the button was first clicked");
    }
    //if the queue of clicked events is empty, just print that the queue is empty!
    if(button.isPressedQueueEmpty() == true) {
        Serial.print("  ButtonClicked Queue is empty!");
    }

    Serial.println(); //print a new line to not clutter up the serial monitor

    if(Serial.available()) { //if the user sent a character
        
        uint8_t data = Serial.read();
        if(data == 'p' || data == 'P') { //if the character is p or P, then pop a value off of the pressed Queue
            button.popPressedQueue();
            Serial.println("Popped PressedQueue!");
        }

        if(data == 'c' || data == 'C') { //if the character is c or C, then pop a value off of the pressed Queue
            button.popClickedQueue();
            Serial.println("Popped ClickedQueue!");
        }
    }
    delay(20); //let's not hammer too hard on the I2C bus
}

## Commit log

2019-06-11 Rename files with gap sizes.
    [Qwiic_Switch-Gap-0.0300.brd, Qwiic_Switch-Gap-0.0300.sch, Qwiic_Switch-Gap-0.0320.brd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]
2019-06-11 Removing files with too large gap
    Gap of 0.03 is still too loose on switch paddles. Removing gaps 0.032 and 0.034.
    [Qwiic_Button-Panel.brd, Qwiic_Switch-Gap-0.0320.brd, Qwiic_Switch-Gap-0.0320.sch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]
2019-07-23 Reworked stack, updated bitwise operators with readable macros
    [Qwiic_Switch.ino]
2019-07-24 Struct-ified the LED handling and moved it to it's own header file
    Also went from byte to uint8_t for cross-platform compatibility
2019-07-24 Update interrupts.ino
    Go from bytes to uint8_t for cross-platform compatibility
2019-07-26 Removed janky debug serial.print()'s
2019-07-29 Removed config for interrupt logic level
    Turns out the board is designed to do active-low only
2019-07-30 Fixed issue where queues would not default to being empty
    [Qwiic_Switch.ino]
2019-07-31 Added ability to switch I2C addresses, and updated documentation
    I2C address selection should be correct based on being on either the Switch or the Button
    [Qwiic_Switch.ino]
2019-08-01 Revert "Added ability to switch I2C addresses, and updated documentation"
    This reverts commit 4302c0fba5622e3d9719b3ecffc95f3a24247165.
    [Qwiic_Switch.ino]
2019-08-01 Device ID and I2C addresses are now selectedable from a #define
2019-08-01 Removed stack-based debounce from interrupts
    It was interfering with the interrupt on button press :/ but everything works on the qwiic button!
2019-08-01 Fixed button debouncing
2019-08-01 Set firmware version equal to 1.0
    This is the production code that is going on the devices
2019-08-09 Fix firmware button debouncing issues
    [Qwiic_Switch.ino]
2019-08-14 Correct I2C address logic to match schematic. Reorder memoryMap to match register map doc.
    [Qwiic_Switch.ino]
2019-08-20 Add debouce to pin change interrupt.
2019-08-20 Declaring Ques as volatile. Removing multiple I2C addresses. Removing multiple hardware defs.
2019-08-20 Use EEPROM put instead of update. Was probably causing EEPROM corruption.
    Update() only handles 8-bit values. Put handles 8, 16, and 32 correctly while calling update() on the 8-bit chunks.
    [Qwiic_Switch.ino]
2019-08-28 Add ADR jumpers. Decrease leaf switch gap to 0.025". Remove old files.
    [Qwiic_Switch.brd, Qwiic_Switch.sch]
2019-08-29 Update schematic with I2C address
    [Qwiic_Switch.brd]
2019-09-06 Corrected bit order of interruptConfig
    This code erases EEPROM settings on Arduino Unos. Found out that the compiler packs bits in an unexpected order.
    [Qwiic_Button.ino]
2019-09-10 Change I2C addres working!
    Moved startI2C call to evaluate no matter the i2c address value in recordSystemSettings function.
2019-09-11 Fixed start i2C bug
    Originally we were calling startI2C everytime recordSystemSettings was called (loop()). Now, we only call startI2C after checking if the I2C address has actually been changed.
    [Qwiic_Button.ino]
2019-09-12 Changed interruptConfigure.status to buttonStatus.eventAvailable
    Whether an event has ocurred is a detail of the current button status, so I changed the registers accordingly. Additionally, changed the interrupt pin logic in the main loop.
2019-09-12 Set interrupt pin to default high
2019-09-17 External interrupts
    Moved the interruptPin logic outside of the updateFlag check. pressedEnable and clickedEnable default to true.
2019-09-18 Update LED AFTER recordSystemSettings
    Fixed weird flashing of LED that occurs in example 3.
    [Qwiic_Button.ino]
2019-09-20 Added EEPROM_erase sketch for uploading code to fresh buttons
    Generated appropriate .hex files and updated .bat file.

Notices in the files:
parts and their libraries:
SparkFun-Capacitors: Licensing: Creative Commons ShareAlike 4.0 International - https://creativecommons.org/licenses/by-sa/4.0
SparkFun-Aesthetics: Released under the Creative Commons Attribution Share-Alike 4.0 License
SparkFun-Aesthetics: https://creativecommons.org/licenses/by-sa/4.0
